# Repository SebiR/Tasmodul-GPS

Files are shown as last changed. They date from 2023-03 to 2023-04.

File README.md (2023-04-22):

# Tasmodul GPS
A module to get live GPS coordinates into MQTT with Tasmota or other home automation systems

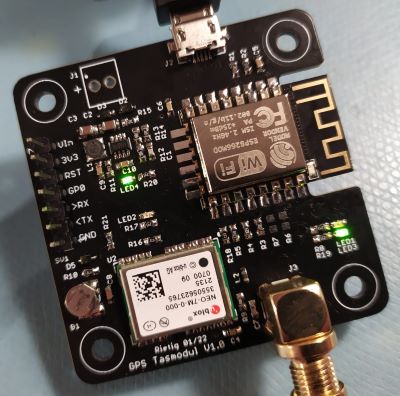
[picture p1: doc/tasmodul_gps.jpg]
GPS


## Features
* SMA connector for external GPS antenna
* Micro USB for powering and data access

## Notes
* The battery (ML414H_IV01E) can be ordered on AliExpress, that's probably the easiest way
* Tasmota does not include GPS capability by default. It has to be compiled with custom parameters to include it

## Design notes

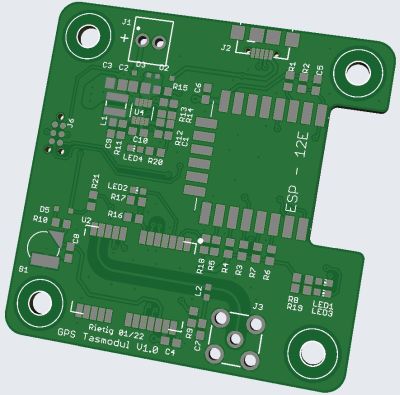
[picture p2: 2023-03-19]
doc/tasmodul_gps_render.jpg

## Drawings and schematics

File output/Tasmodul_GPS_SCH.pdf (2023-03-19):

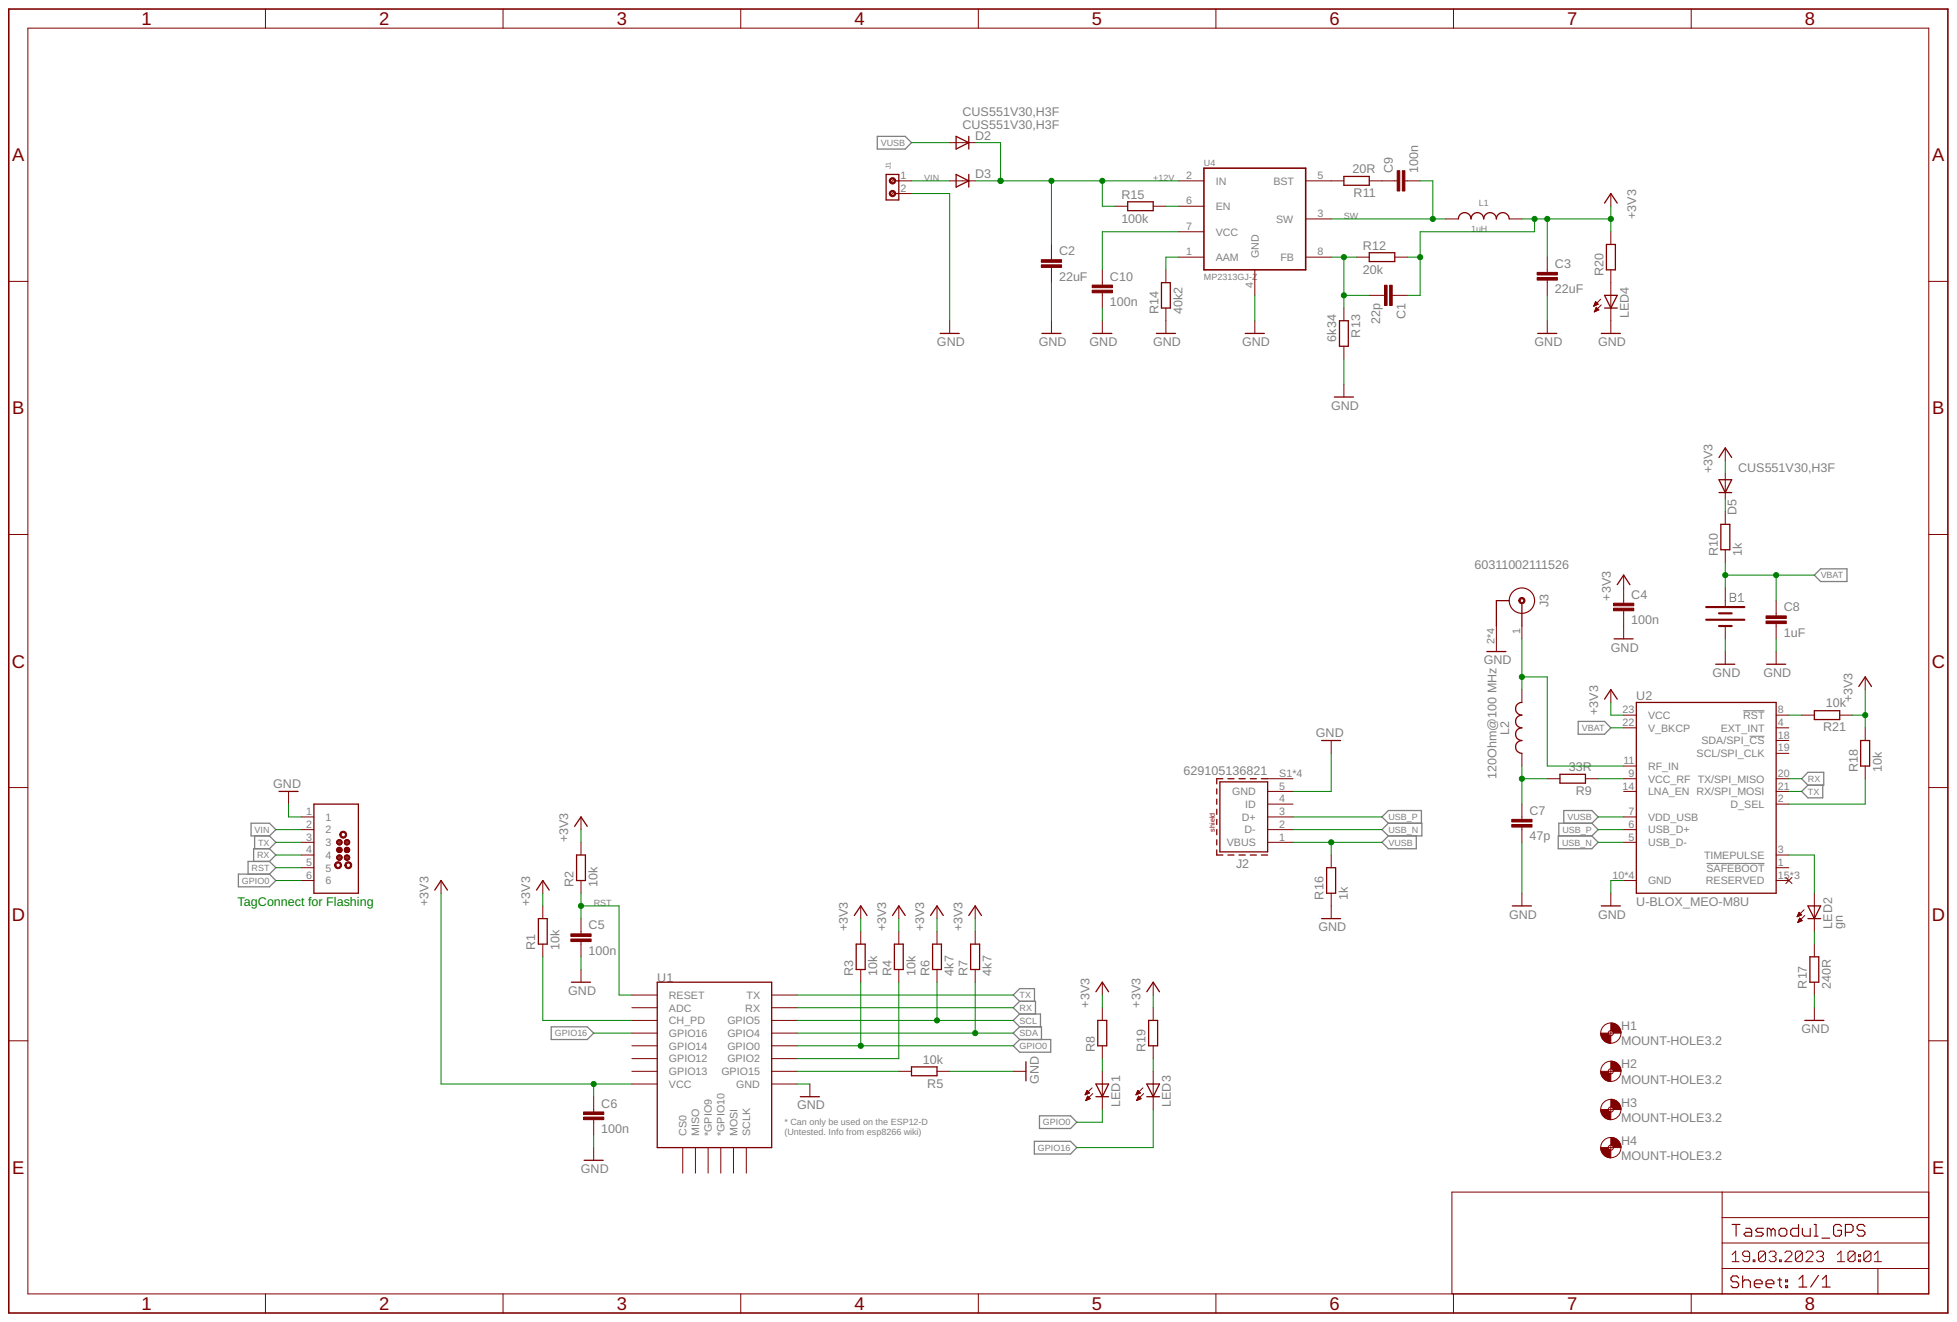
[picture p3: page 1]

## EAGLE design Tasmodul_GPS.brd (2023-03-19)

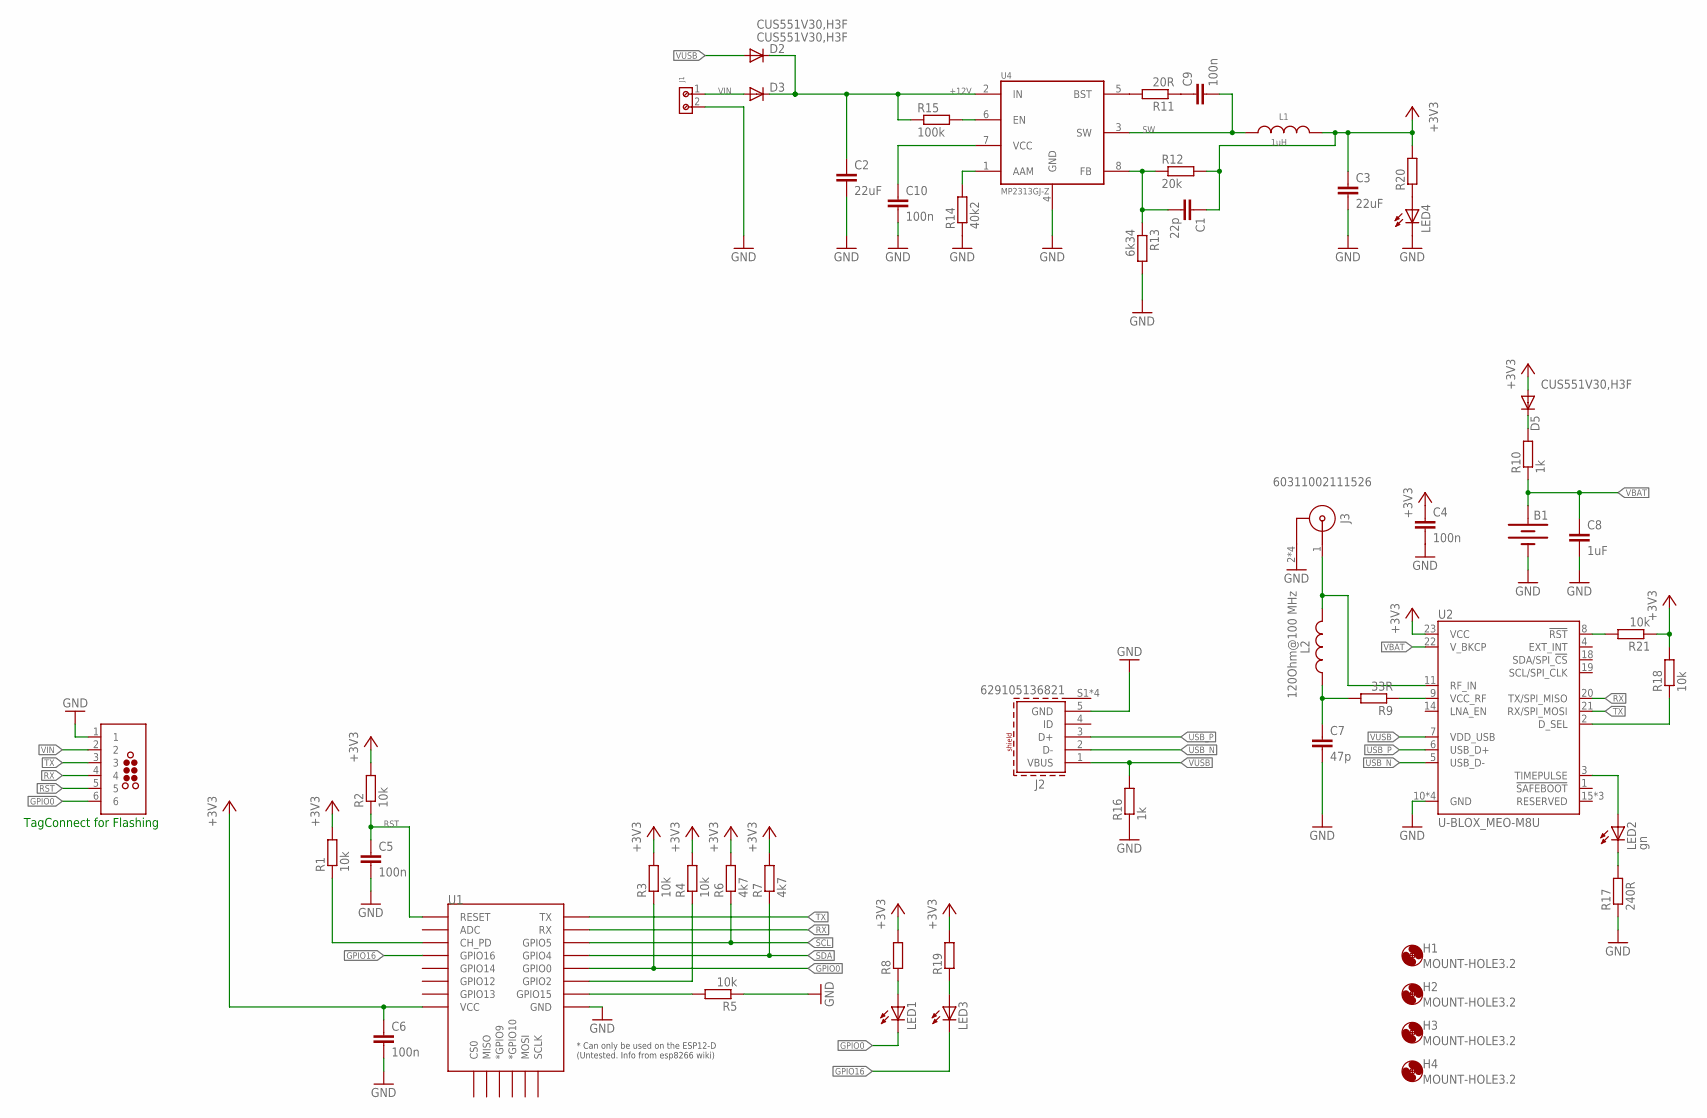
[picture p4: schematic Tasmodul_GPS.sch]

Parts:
B1: 6.8MM_COIN_CELL; ML414H_IV01E
C1: 22p; C0603
C2, C3: 22uF; C0805
C4, C5, C6, C9, C10: 100n; C0603
C7: 47p; C0603
C8: 1uF; C0603
D2, D3, D5: CUS551V30,H3F; SOD323-R
H1, H2, H3, H4: MOUNT-HOLE3.2; 3,2
J1: 691210910002
J2: 629105136821
J3: 60311002111526
J6: TC2030-MCP-NL
L1: 1uH; WE-TPC_2811_OLD
L2: 120Ohm@100 MHz; WE-CBF_0603(W=2.2)
LED1, LED3, LED4: LEDCHIP-LED0603; CHIP-LED0603
LED2: gn; CHIP-LED0603
R1, R2, R3, R4, R5, R18, R21: 10k; R0603
R6, R7: 4k7; R0603
R8, R19, R20: R-EU_R0603; R0603
R9: 33R; R0603
R10, R16: 1k; R0603
R11: 20R; R0603
R12: 20k; R0603
R13: 6k34; R0603
R14: 40k2; R0603
R15: 100k; R0603
R17: 240R; R0603
U1: ESP12ESMD; ESP12E-SMD
U2: U-BLOX_MEO-M8U; NEO-M9N/M8T/M8U
U4: MP2313GJ-Z; TSOT23-8_MPS

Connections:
+3V3: C1.1, C3.1, C4.1, C6.1, D5.A, L1.2, R1.2, R2.2, R3.2, R4.2, R6.2, R7.2, R8.2, R12.2, R18.2, R19.2, R20.2, R21.1, U1.VCC, U2.23 (VCC)
+12V: C2.1, D2.C, D3.C, R15.1, U4.2 (IN)
GND: B1.-, C2.2, C3.2, C4.2, C5.2, C6.2, C7.2, C8.2, C10.2, J1.2, J2.5 (GND), J3.2, J3.3 (2), J3.4 (2), J3.5 (2), J6.1, LED4.C, R5.1, R13.2, R14.1, R16.1, R17.1, U1.GND, U2.10 (GND), U2.12 (GND), U2.13 (GND), U2.24 (GND), U4.4 (GND)
GPIO0: J6.6, LED1.C, R3.1, U1.GPIO0
GPIO16: LED3.C, U1.GPIO16
unnamed: LED1.A, R8.1
unnamed: LED2.C, R17.2
unnamed: J3.1, L2.2, U2.11 (RF_IN)
unnamed: R21.2, U2.8 (!RST)
unnamed: R1.1, U1.CH_PD
unnamed: R5.2, U1.GPIO15
unnamed: R4.1, U1.GPIO2
unnamed: D5.C, R10.2
unnamed: R11.2, U4.5 (BST)
unnamed: C9.1, R11.1
unnamed: R9.1, U2.9 (VCC_RF)
unnamed: C1.2, R12.1, R13.1, U4.8 (FB)
unnamed: C10.1, U4.7 (VCC)
unnamed: R14.2, U4.1 (AAM)
unnamed: R15.2, U4.6 (EN)
unnamed: C7.1, L2.1, R9.2
unnamed: LED2.A, U2.3 (TIMEPULSE)
unnamed: R18.1, U2.2 (D_SEL)
unnamed: LED3.A, R19.1
unnamed: LED4.A, R20.1
RST: C5.1, J6.5, R2.1, U1.RESET
RX: J6.4, U1.RXD0 (RX), U2.20 (TX/SPI_MISO)
SCL: R6.1, U1.GPIO5
SDA: R7.1, U1.GPIO4
SW: C9.2, L1.1, U4.3 (SW)
TX: J6.3, U1.TXD0 (TX), U2.21 (RX/SPI_MOSI)
USB_N: J2.2 (D-), U2.5 (USB_D-)
USB_P: J2.3 (D+), U2.6 (USB_D+)
VBAT: B1.+, C8.1, R10.1, U2.22 (V_BKCP)
VIN: D3.A, J1.1, J6.2
VUSB: D2.A, J2.1 (VBUS), R16.2, U2.7 (VDD_USB)

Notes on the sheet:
TagConnect for Flashing

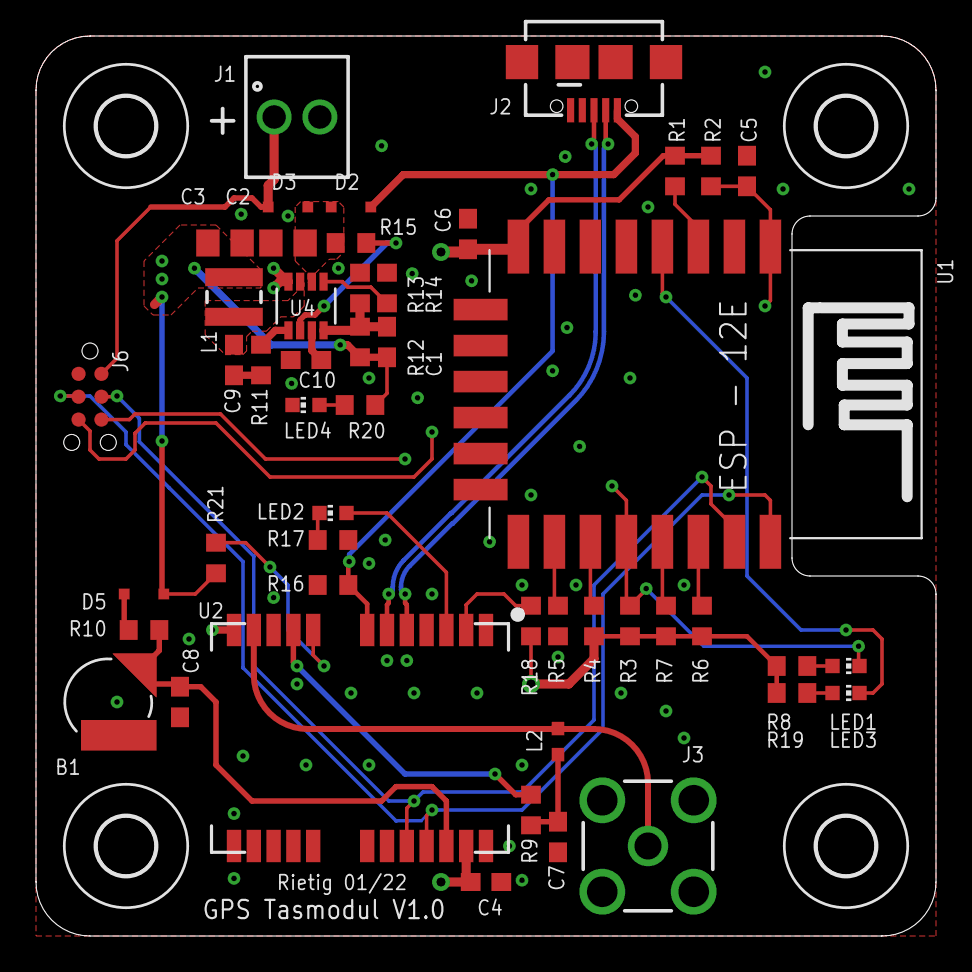
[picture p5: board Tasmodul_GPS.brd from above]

Board: 4 copper layers, 50.0 x 50.0 mm, 52 parts (0 on the bottom side), 36 nets.

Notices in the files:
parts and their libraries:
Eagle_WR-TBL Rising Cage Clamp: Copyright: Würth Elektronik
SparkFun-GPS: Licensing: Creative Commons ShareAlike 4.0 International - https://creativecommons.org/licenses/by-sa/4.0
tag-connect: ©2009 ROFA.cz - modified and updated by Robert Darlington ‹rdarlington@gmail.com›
